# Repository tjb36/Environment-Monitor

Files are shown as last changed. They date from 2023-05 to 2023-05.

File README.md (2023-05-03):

# Environment-Monitor

This is a PCB project to take the ±10V readings from a 3 channel Bartington magnetometer, read them with an ADC and Arduino, and finally post the data over ethernet to a remote InfluxDB database.





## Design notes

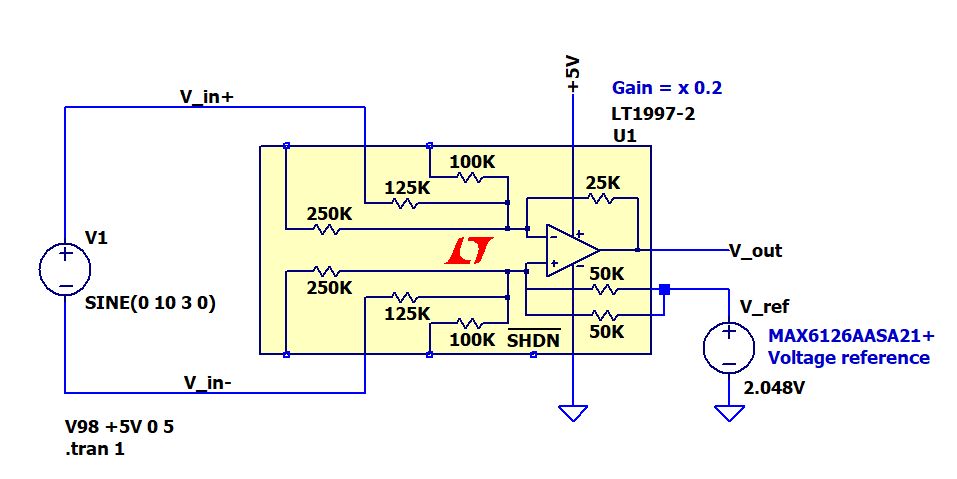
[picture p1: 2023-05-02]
Environment_Monitor_PCB_FILES/Schematic.jpg

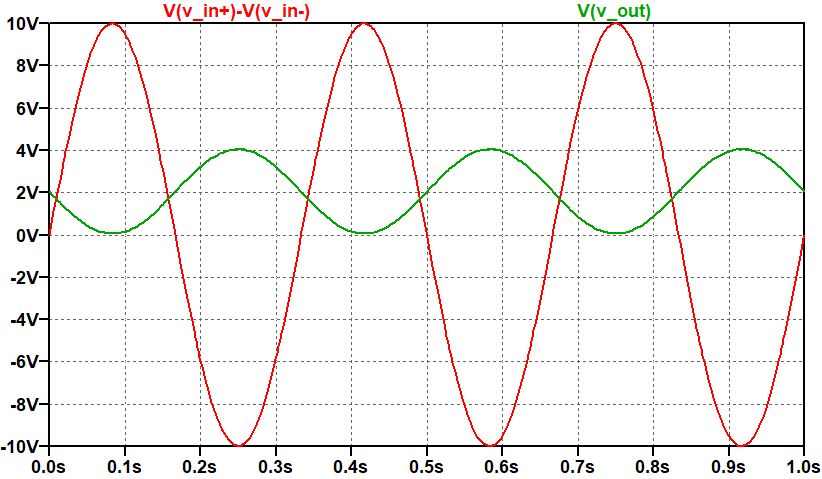
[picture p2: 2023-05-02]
Environment_Monitor_PCB_FILES/waveform.jpg

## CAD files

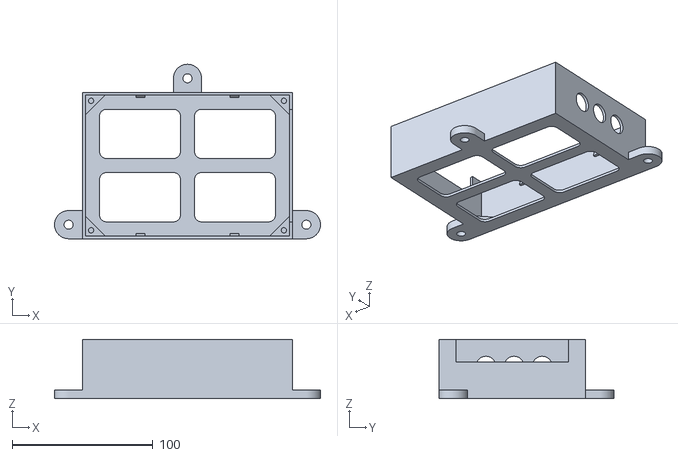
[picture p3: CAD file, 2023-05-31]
Environment_Monitor_CAD/Environment_Monitor_Case-Main Frame.stl
189.0 x 124.0 x 42.0

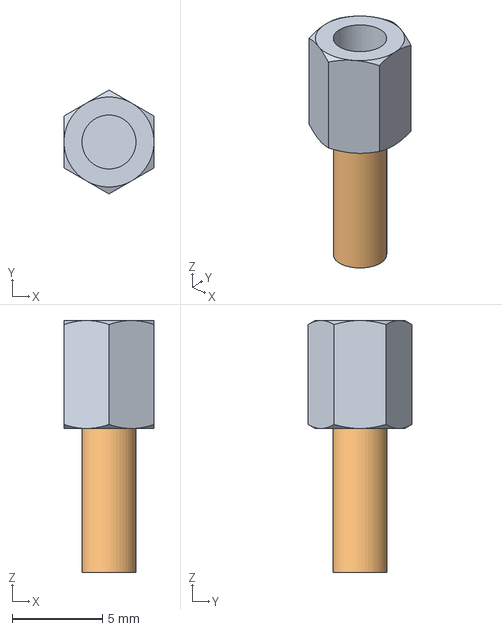
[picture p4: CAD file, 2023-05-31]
Environment_Monitor_CAD/3D/Standoff mf - M3 x 6 across flats 5mm.step
5.00 x 5.77 x 14.0 mm

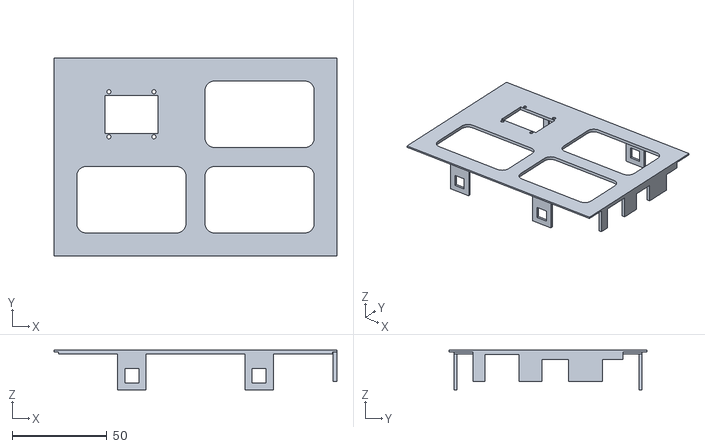
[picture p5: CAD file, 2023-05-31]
Environment_Monitor_CAD/Environment_Monitor_Case-Case Lid.stl
149.0 x 104.0 x 21.0

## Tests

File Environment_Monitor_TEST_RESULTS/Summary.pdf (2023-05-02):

Environment Logger Summary,

# Tests, and Calibration

### T. Barrett

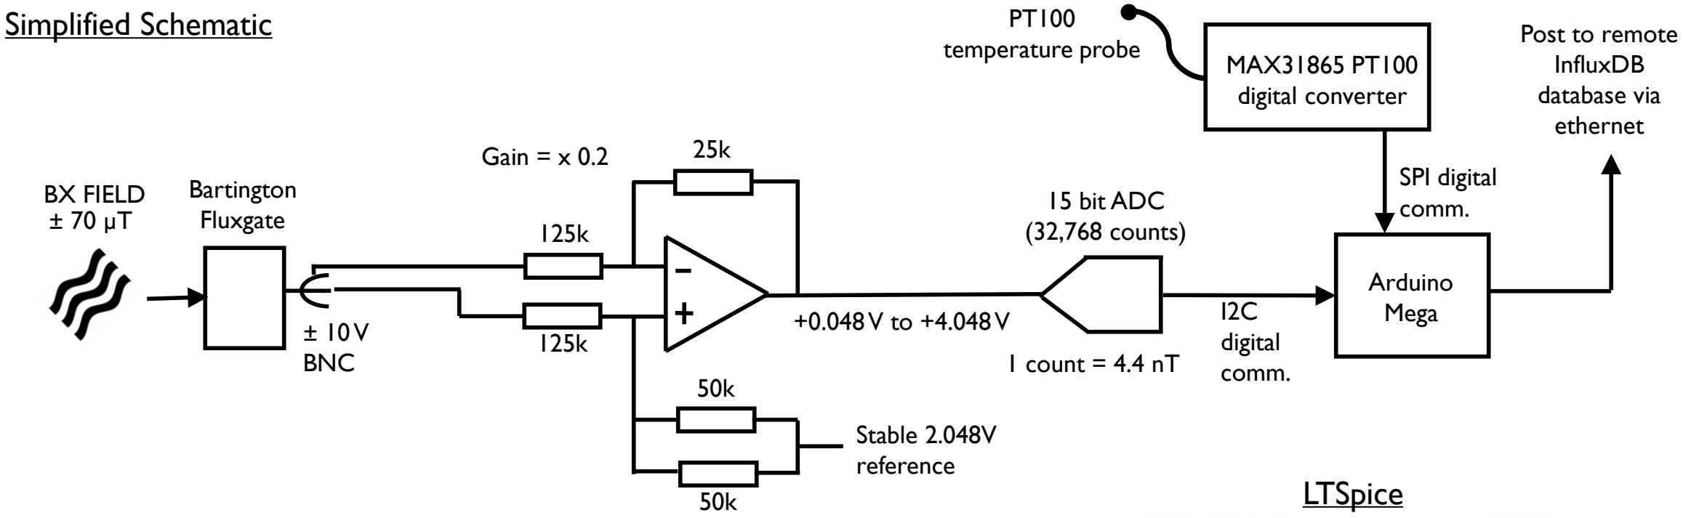
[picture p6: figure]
Stable 2.048V reference; 1 count = 4.4 nT; Bartington; Fluxgate; ± 10 V BNC; digital comm.; Arduino Mega; Post to remote InfluxDB database via ethernet; 15 bit ADC (32,768 counts); Gain = x 0.2; BX FIELD; Simplified Schematic; LTSpice; MAX31865 PT100 digital converter; PT100 temperature probe; SPI digital comm.
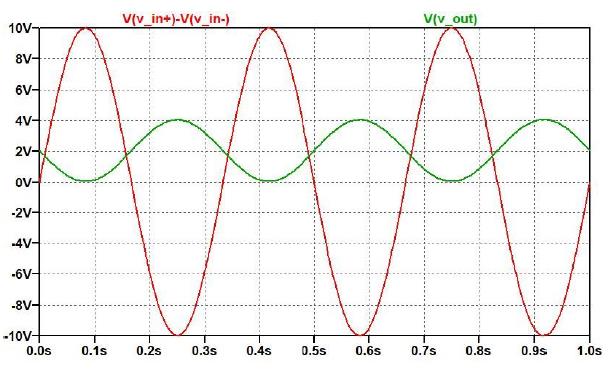
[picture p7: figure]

Repeat for BY on channel 2

Repeat for BZ on channel 3

…

…

Microcontroller Pins Required

ADS1115 (4 channel ADC)

- SCL (serial clock)
- SDA (serial data)
- VDD (+5V)
- GND

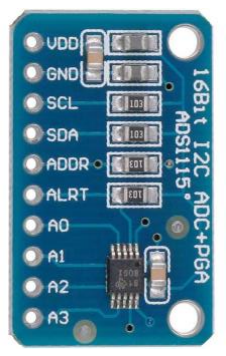
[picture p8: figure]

MAX31865 (PT100 amplifier)

- CLK
- MISO
- MOSI
- CS
- VDD (+5V)
- GND

2-wire I2C

SPI

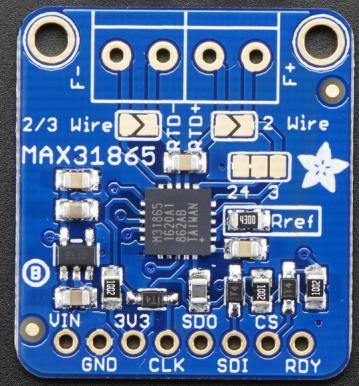
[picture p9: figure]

- Can use hardware SPI or software SPI. Hardware SPI is faster, because there is an internal peripheral device designed to shift the bits out and generate the signals.

Mini W5100 (LAN chip)

SPI

- CLK
- MISO
- MOSI

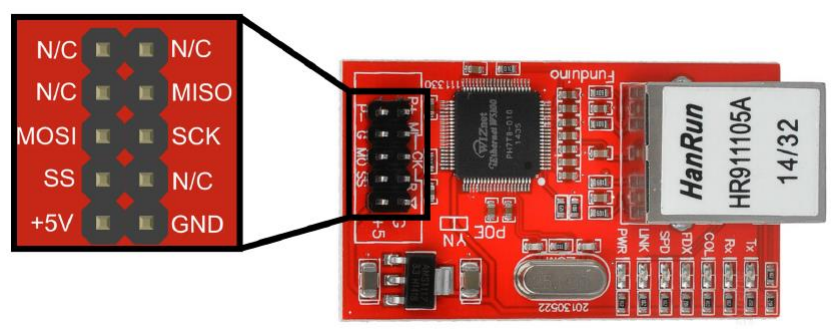
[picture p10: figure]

- CS (use pin 10, because it’s defined in Arduino library)
- VDD (+5V)
- GND
- Arduino Mega hardware SPI pins: | CLK
| MISO
| MOSI 51

50

52

- Arduino Mega I2C pins: SCL SDA D20 D21

- Arduino Nano has 32 KB flash memory (2 KB used by bootloader). So, 30,720 bytes available for program. This is equivalent to 30.72 kilobytes, or 30 kibibytes.
- Arduino Mega has 256 KB memory (8 KB used by bootloader). So should be 248 kibibytes available to use. Which is 248 x 1024 = 253,952 bytes.
- Ethernet sketch requires 18,294 bytes
- Temperature sketch requires 4,004 bytes
- ADC sketch requires 3,236 bytes
- Basic OLED sketch requires 7,016 bytes
- Total is 32,550 bytes…
(more than available on Nano… need to use Arduino Mega)

Microcontroller Memory Required

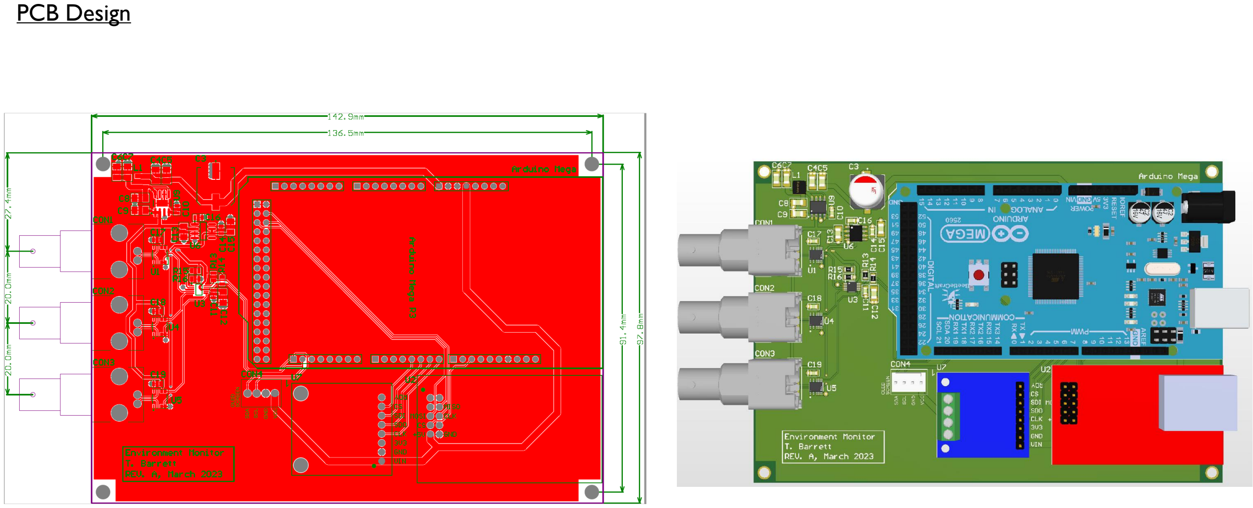
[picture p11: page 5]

PCB Design

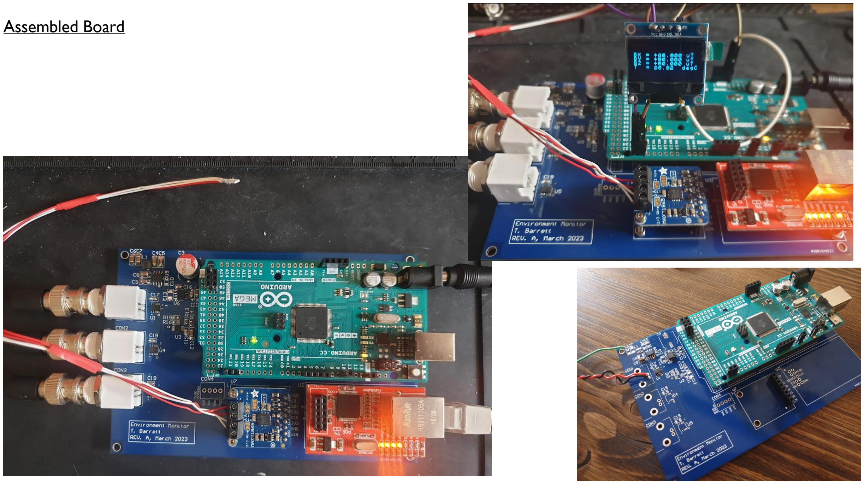
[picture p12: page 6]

Assembled Board

Structure of Firmware

Startup functions → Initialise ethernet chip, ADC, and PT100 converter

Collect N readings from ADC channel 1 and take average (takes 1.73 ms per reading, e.g. 173ms for 100 readings)

Collect N readings from ADC channel 2 and take average (takes 1.73 ms per reading, e.g. 173ms for 100 readings)

Collect N readings from ADC channel 3 and take average (takes 1.73 ms per reading, e.g. 173ms for 100 readings)

Obtain PT100 reading (takes 77 ms)
Connect to remote InfluxDB server, post data, read response, disconnect from server (takes 25 ms)

MAIN LOOP (every X seconds, e.g. every 20 sec)

Update OLED display screen

~620 ms

Power On

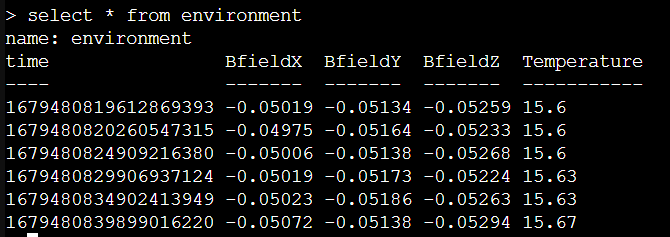
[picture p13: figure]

Data format in InfluxDB
(each datapoint is a field, with no tags).

All fields share a common time-stamp (may be useful later if wanting to do correlation, etc)

ADC Calibration of all channels

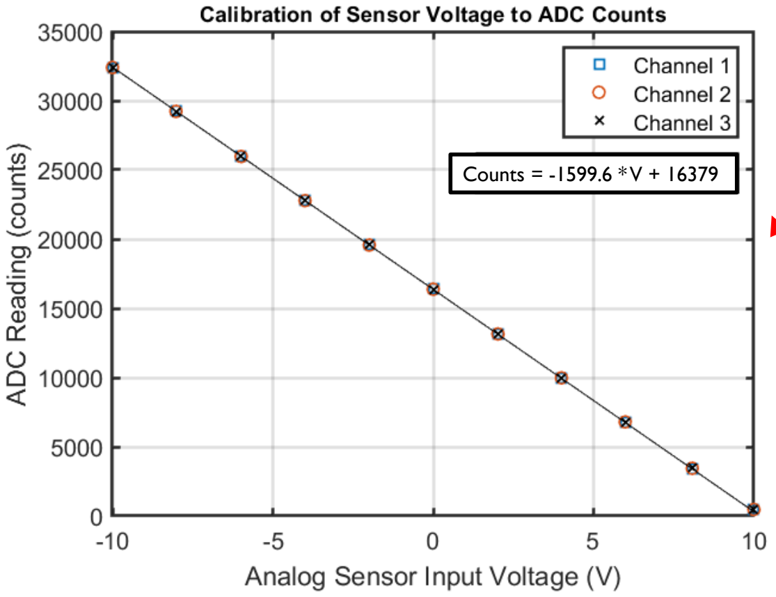
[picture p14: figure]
Counts = -1599.6 * V + 16379

Expected 0.000125 volts per bit from ADC setting gain=1 This is 8000 counts per volt.
Expected additional gain of 0.2 from LT1997-2 funnel amplifier

So expect: 8000 x 0.2 = 1600 counts / volt
This is close to the measured value of 1599.6 counts / volt

Although the ADS1115 ADC is technically a 16 bit ADC (and should therefore go up to 65,536 counts), this is only true when working in differential mode. In that case, one of the 16 bits is the sign bit, and the other 15 bits are for data. However, differential mode requires dedicating x2 of the ADC inputs, and I would need to have then 6 channels available for all 3 magnetic field directions. The ADC only has 4 channels though, so to avoid needing a second ADC, I am running each channel in single-ended mode. This means you can never get negative values, and so effectively sacrifice the sign bit, leaving an effective 15 bit resolution (32,768 values).

Note:

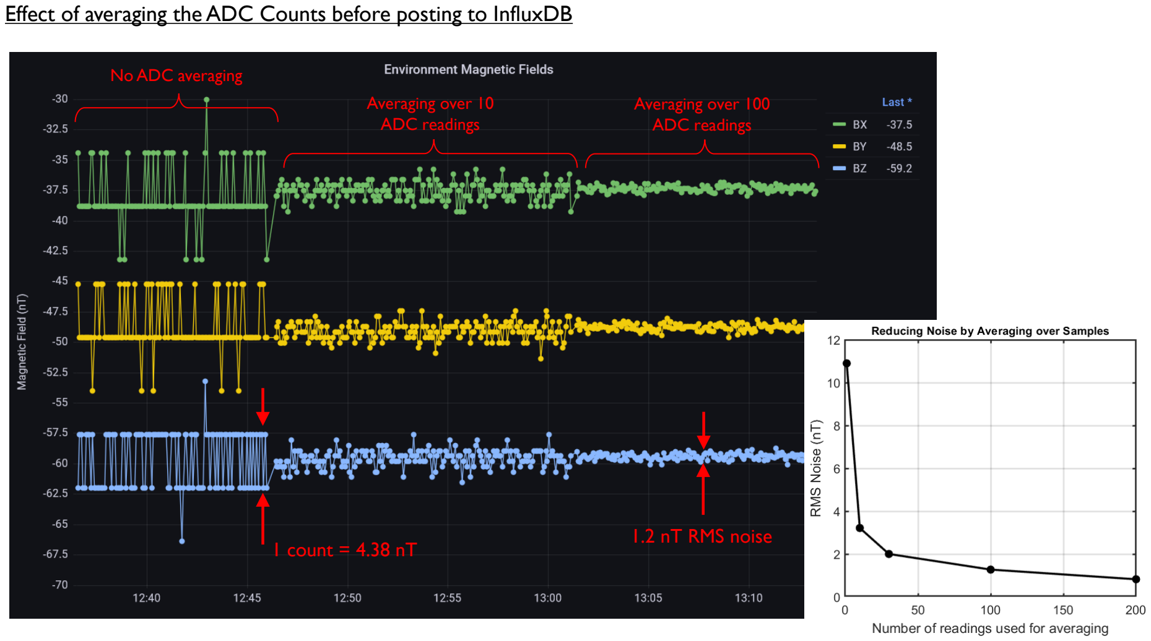
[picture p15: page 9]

Averaging over 100
ADC readings

Averaging over 10
ADC readings

No ADC averaging

1 count = 4.38 nT

Effect of averaging the ADC Counts before posting to InfluxDB

1.2 nT RMS noise


Measuring a 20 Hz sine wave | Measuring a 50 Hz sine wave
Measuring a 100 Hz sine wave | Measuring a 200 Hz sine wave (some aliasing)


- Max and min counts
seems to be around
32330 and 520 counts

→ means I am able to
capture the full +-10V
range successfully.
- 5 Hz sine wave, 20 V p-p (+-10V) | • Measuring the time to collect 10 values from ADC:
- Corresponds to 577 samples / second (should be able to measure up to 288 Hz signals without aliasing)


- BZ changed by 12 nT when Temperature went from 16 to 35 °C
- BX changed by 6 nT when Temperature went from 16 to 35 °C
- BZ changed by 12 nT when Temperature went from 35 to 52 °C
- BX changed by 5 nT when Temperature went from 35 to 52 °C
- BZ changes by 12 nT in 18°C, or 0.67 nT / °C
- BX changes by 6 nT in 18°C, or 0.33 nT / °C
- Applied a BX field of -34990 nT (5V) , and a BZ field of 0 nT.
- At 50°C, we can expect a change of ~12-24 nT from room temperature. This corresponds to 2.5 – 5.5 ADC counts.
- LT1997-2 has a gain error of 1 ppm/°C (0.2 ppm/°C typical).

ADS1115 datasheet says
we can expect 0.015%
change in gain when
increasing from room
temperature up to 50°C

Checking Behaviour of System when Heated to 50°C


Temperature Dependence of Calibration Factors

- A temperature-dependent calibration factor was therefore included in the firmware. (i.e. first we measure the temperature, and then calculate the most appropriate calibration factors – offset and slope - to use)

Behaviour of system when heated to 50°C after adding temperature-dependent calibration


Since the system is heated up fast (in an oven), the PT100 probe heats up faster than the analog circuitry on the PCB, and so there is a delay of around 5 minutes before the calibration becomes accurate.

In the real system, when dealing with slow changes to the room temperature, this will not be present.

The error in the magnetic field reading is now less than 1nT at 50 °C.

This is a big improvement on the error of 24nT before, when the temperature –dependent calibration was not used.

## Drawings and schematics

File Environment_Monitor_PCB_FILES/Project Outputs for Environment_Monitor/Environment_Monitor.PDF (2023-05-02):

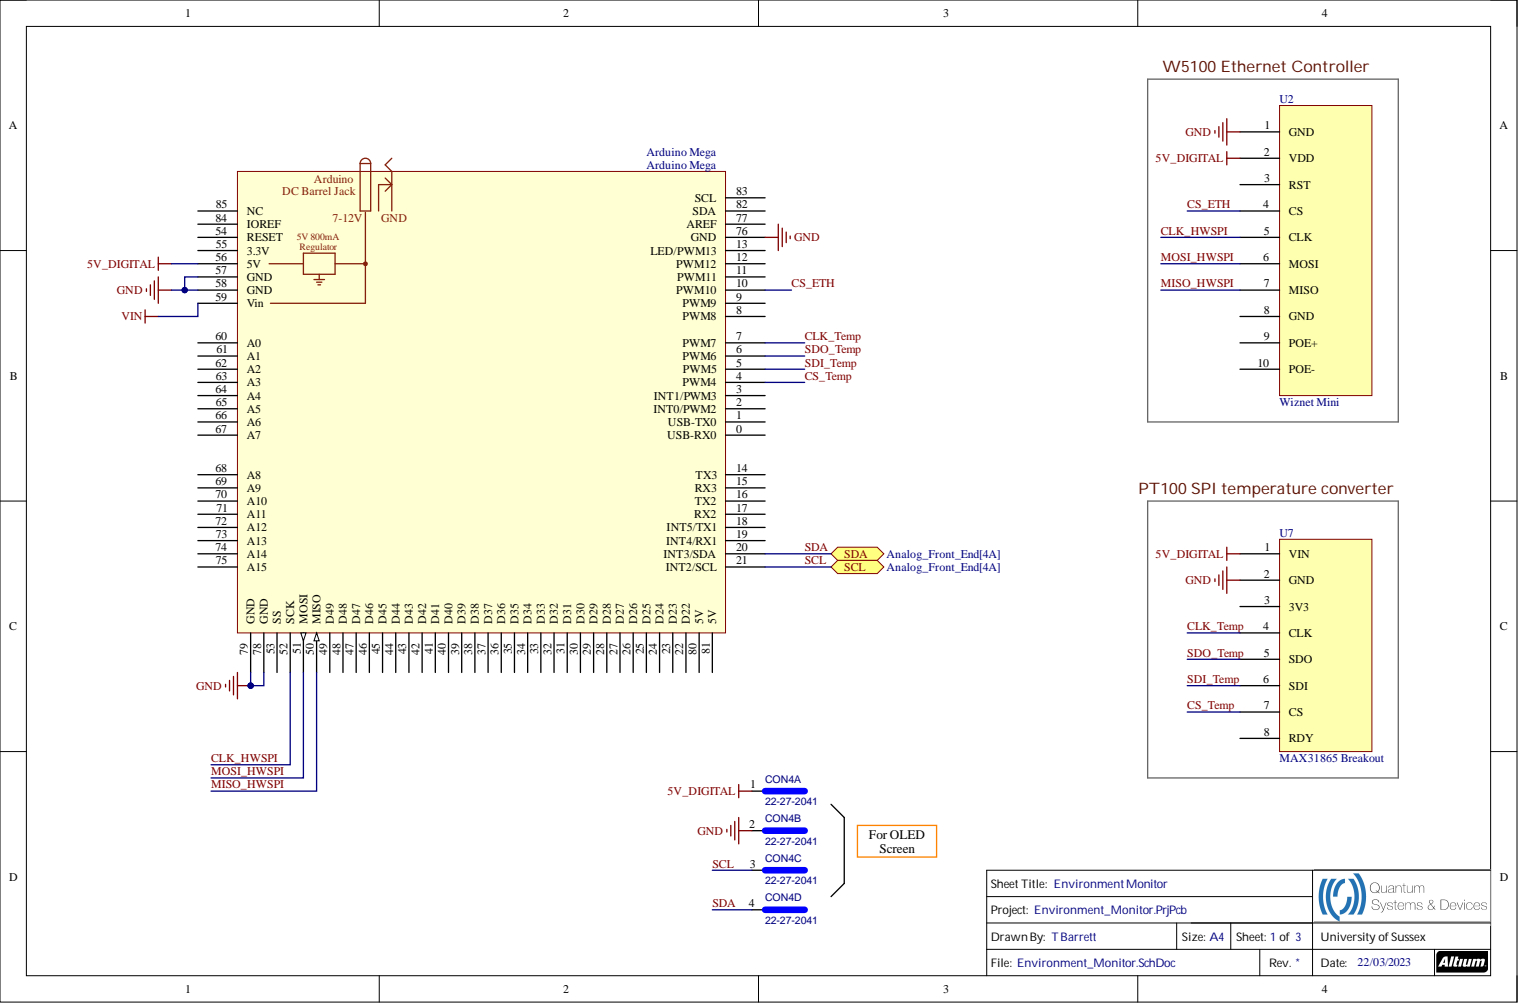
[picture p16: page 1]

D22 22 D23 23 D24 24 D25 25 D26 26 D27 27 D28 28 D29 29 D30 30 D31 31 D32 32 D33 33 D34 34 D35 35 D36 36 D37 37 D38 38 D39 39 D40 40 D41 41 D42 42 D43 43 D44 44 D45 45 D46 46 D47 47 D48 48 D49 49 MISO 50 MOSI 51 SCK 52 SS 53

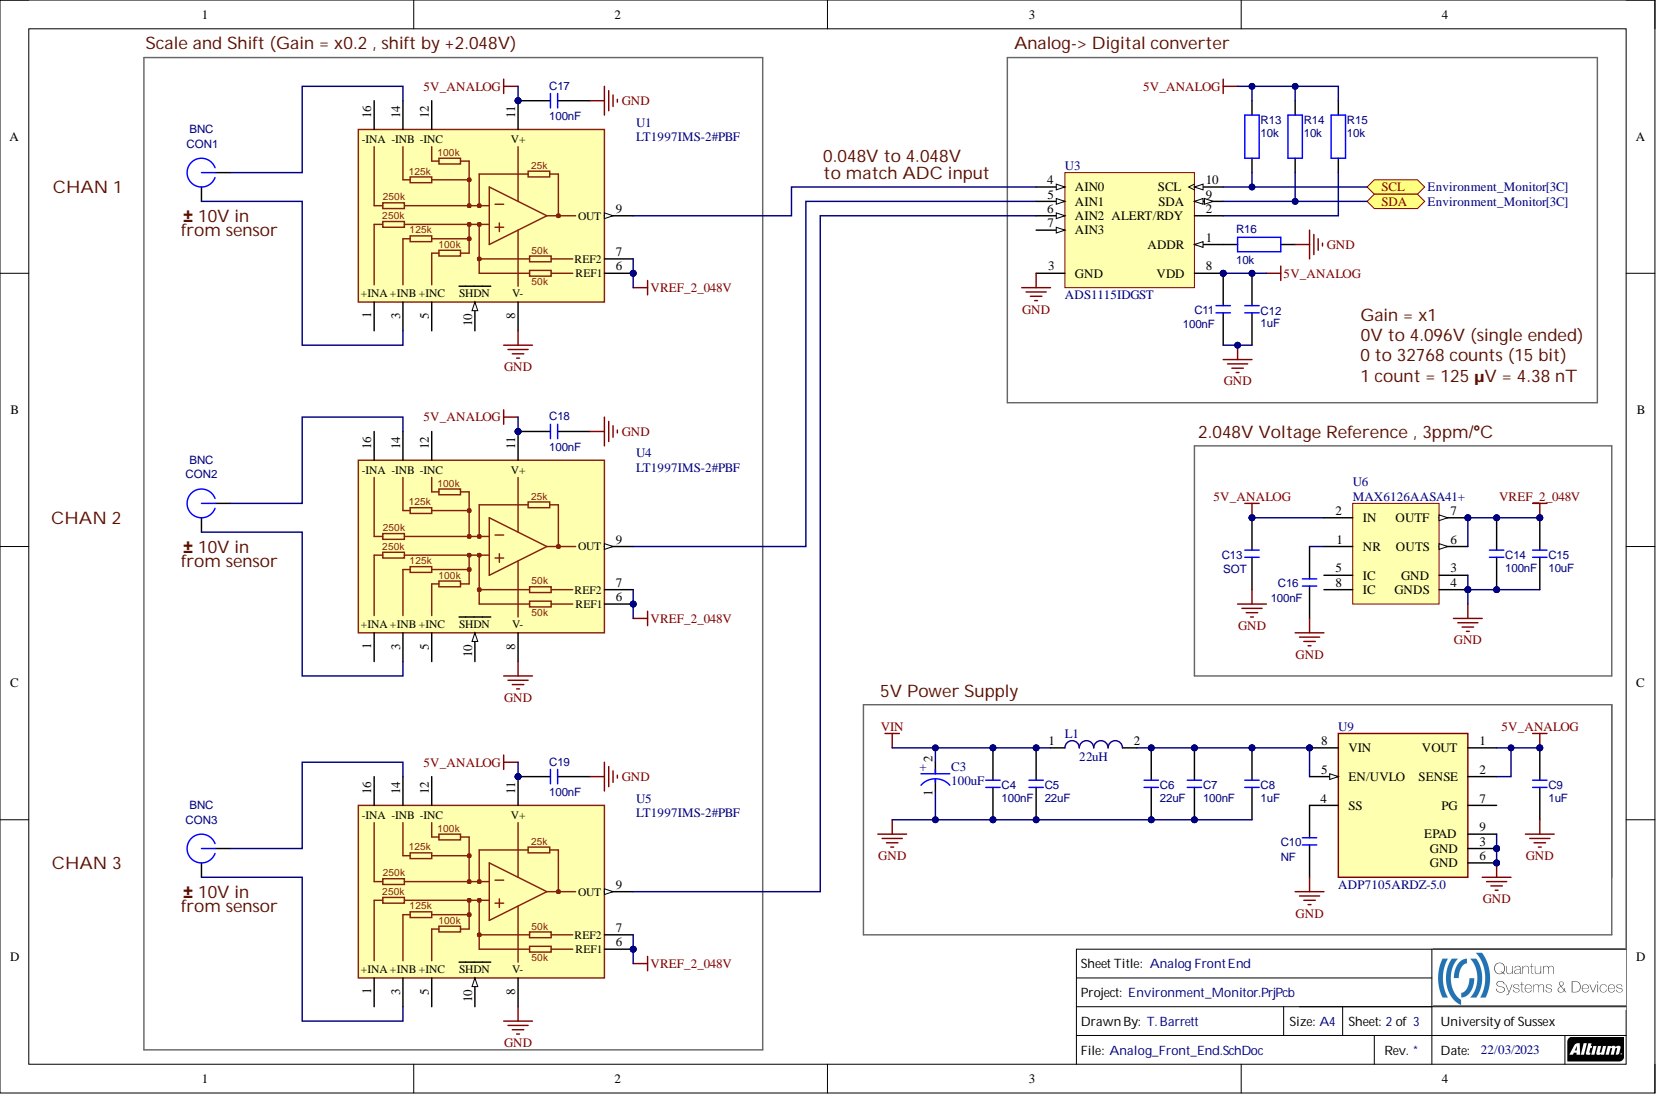
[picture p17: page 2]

6 REF2 7 | G | 7

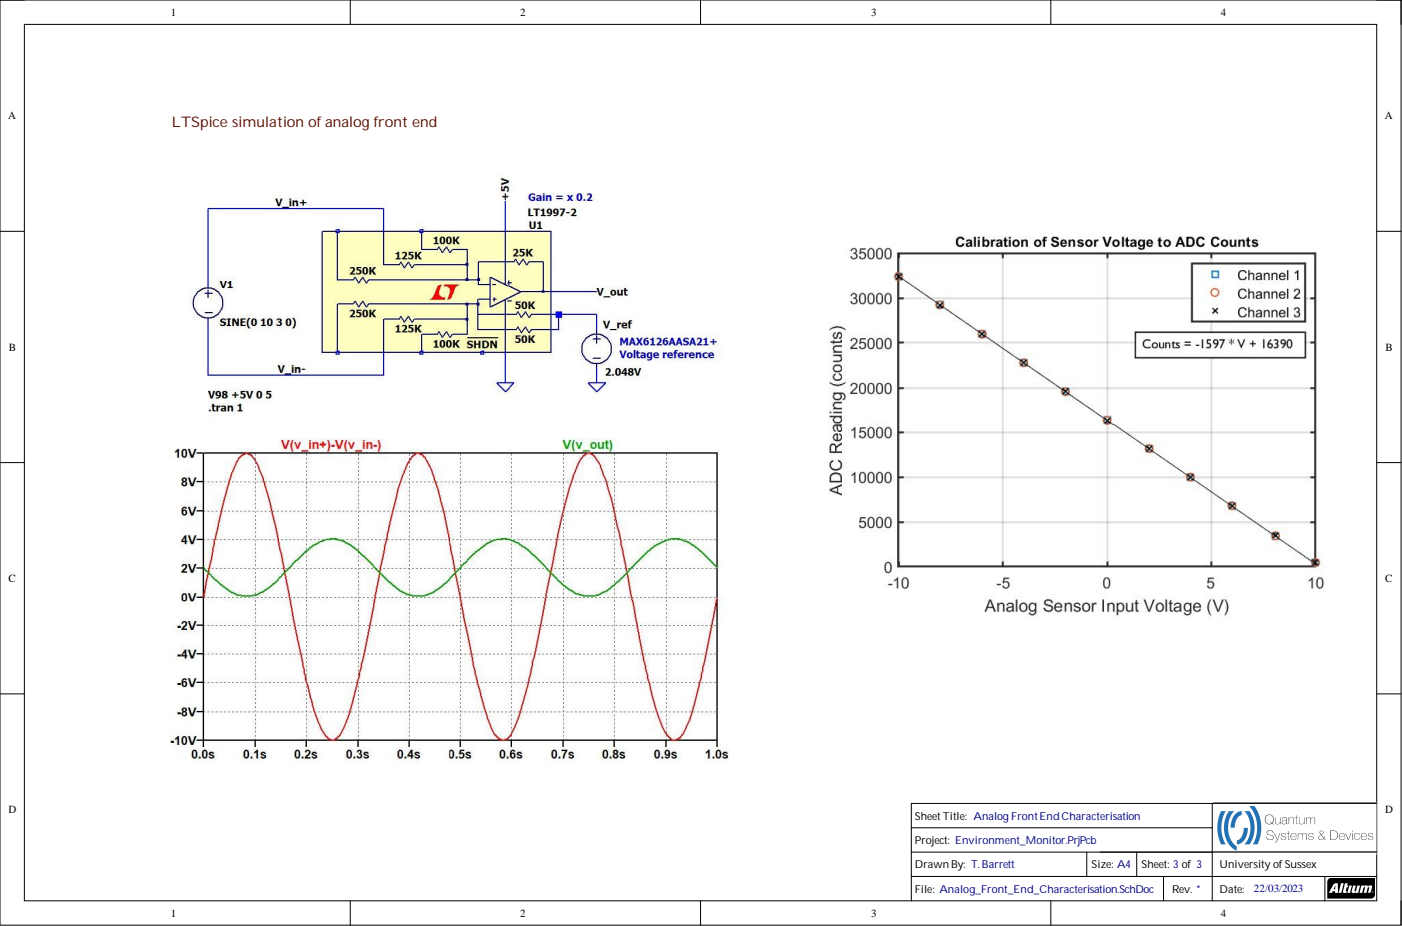
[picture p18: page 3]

LTSpice simulation of analog front end

Analog Front End Characterisation

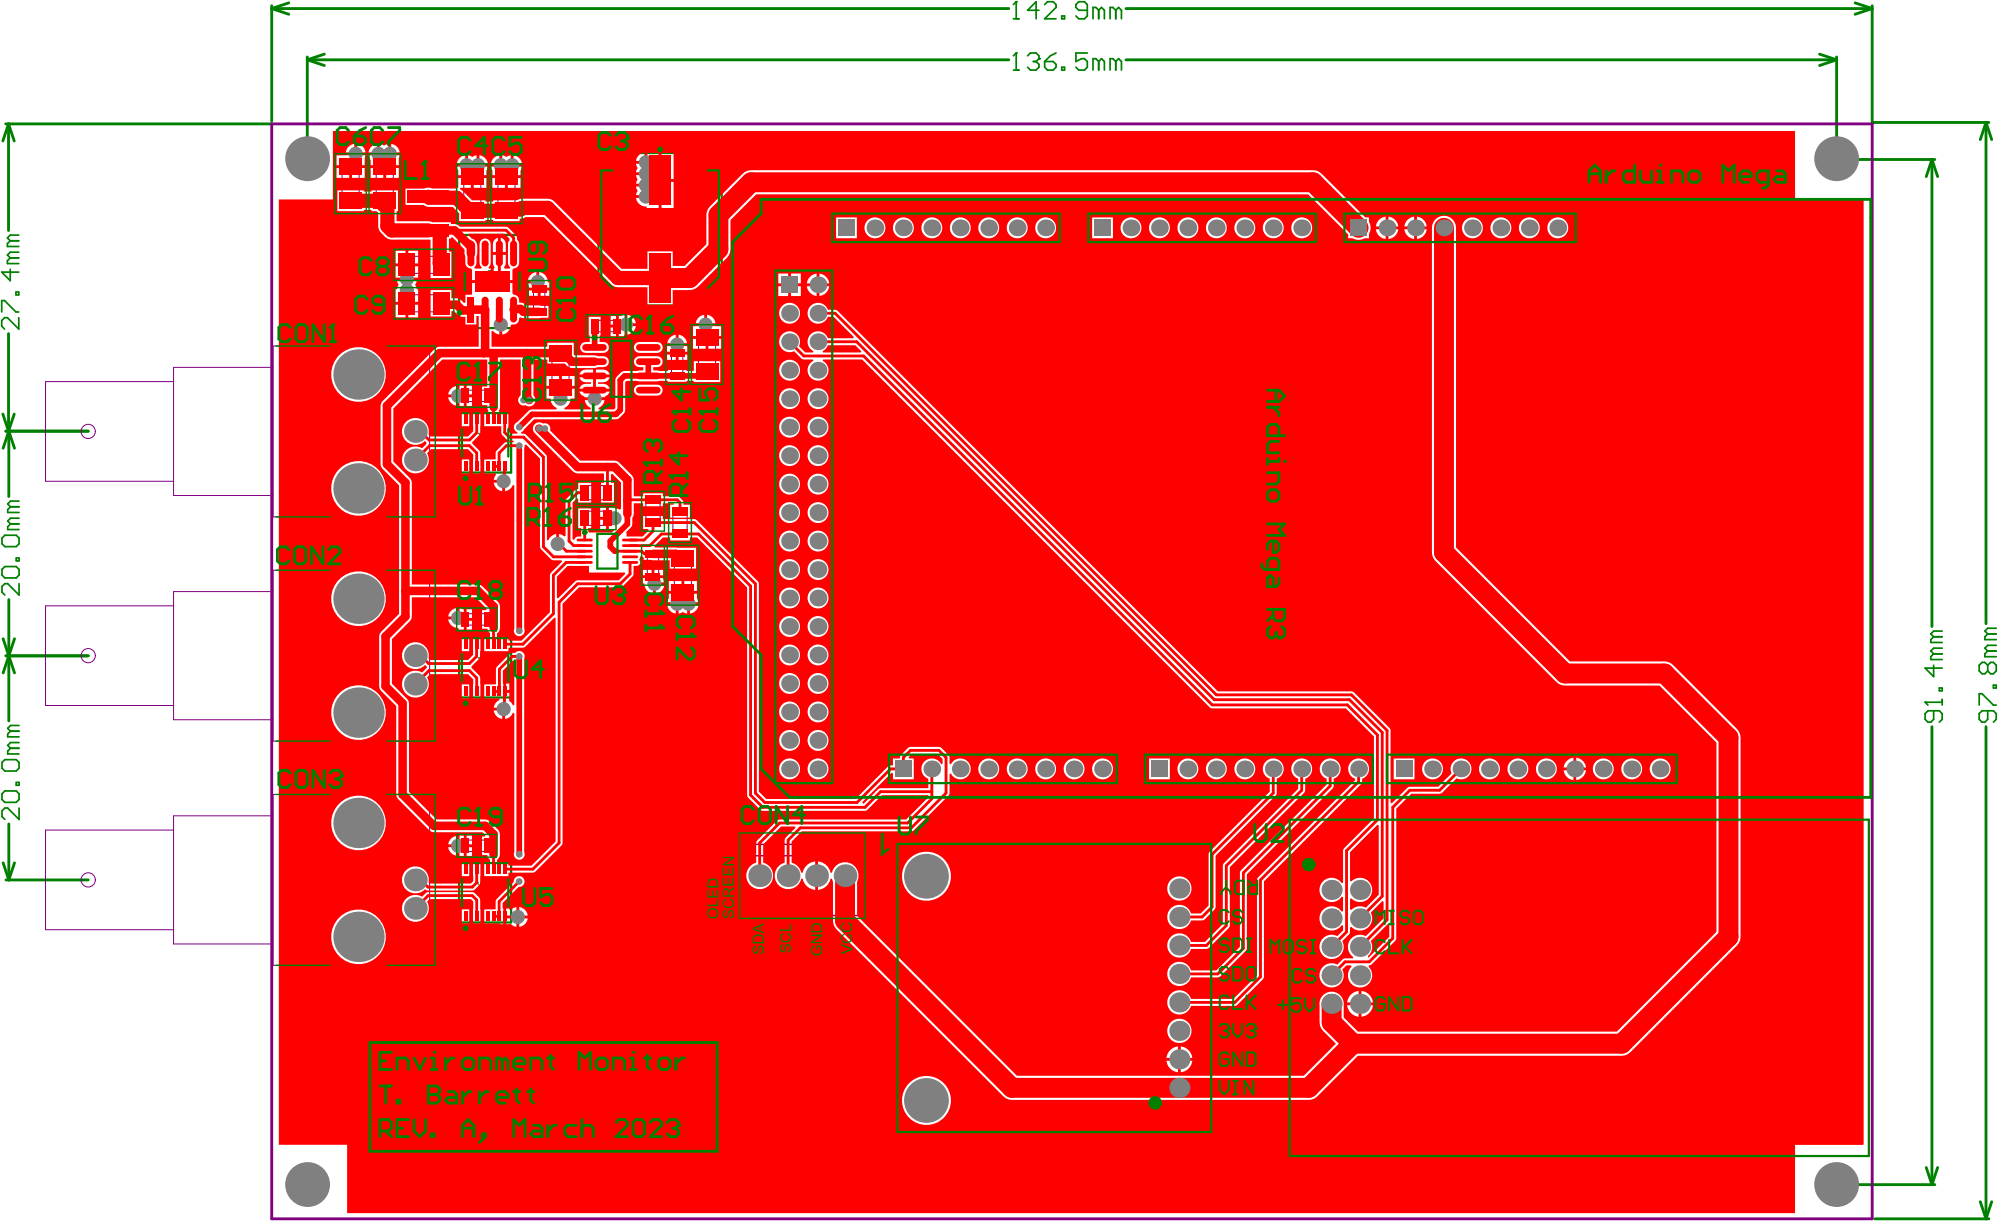
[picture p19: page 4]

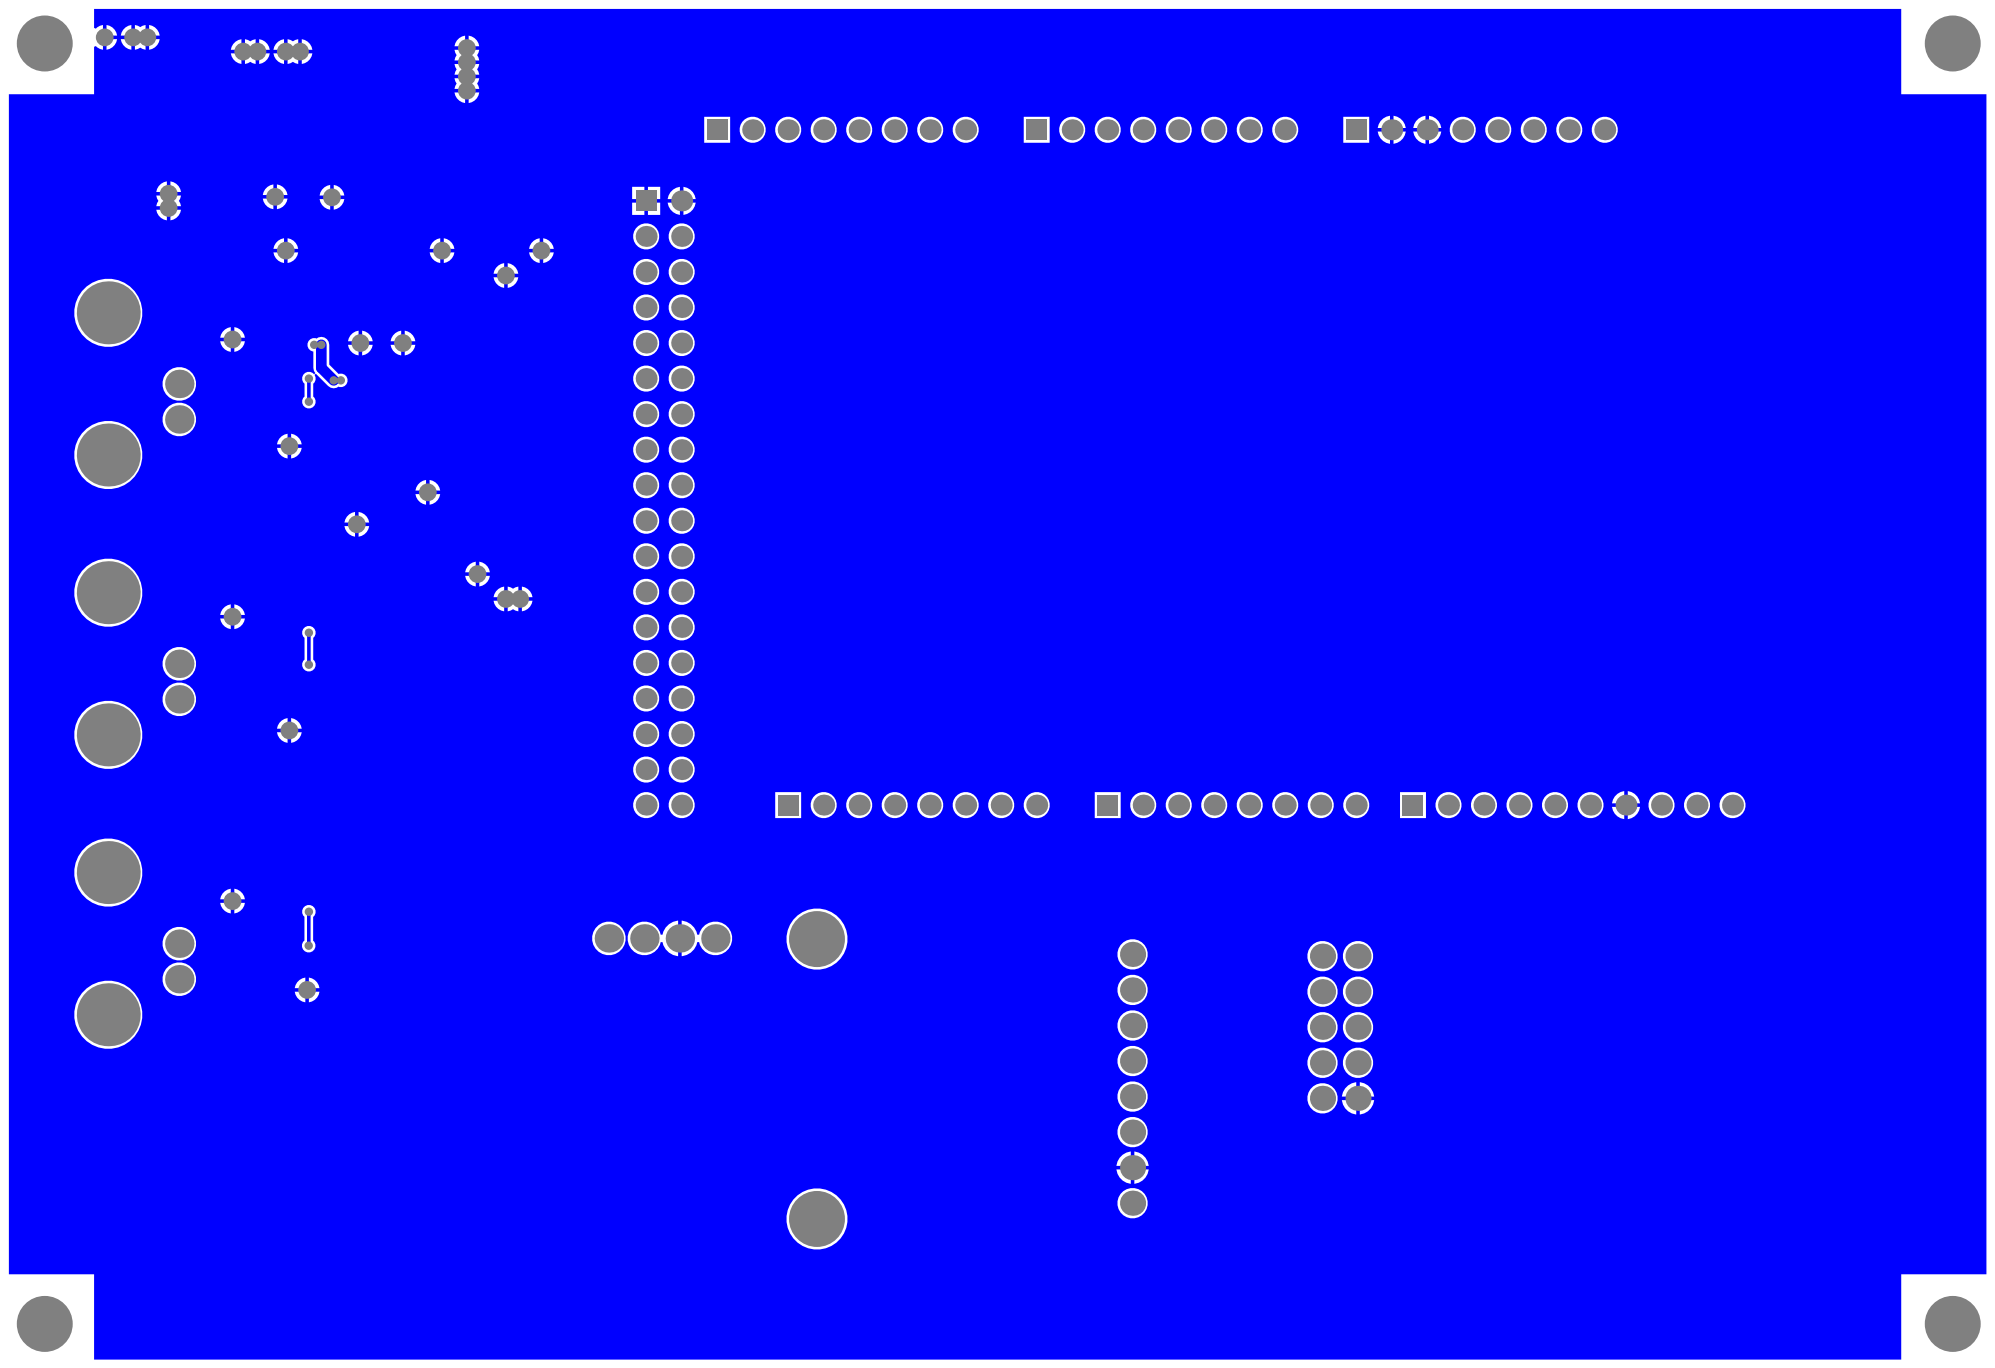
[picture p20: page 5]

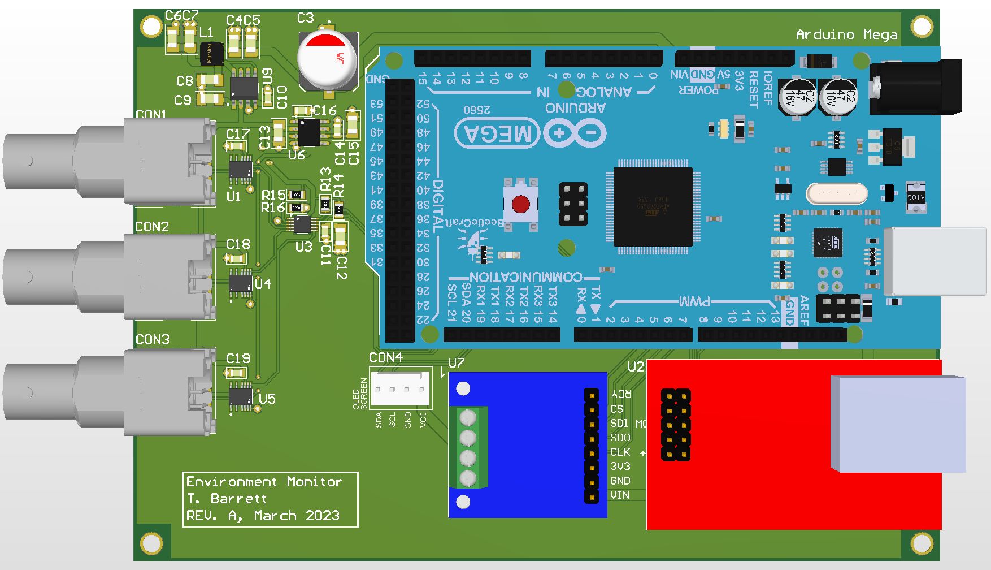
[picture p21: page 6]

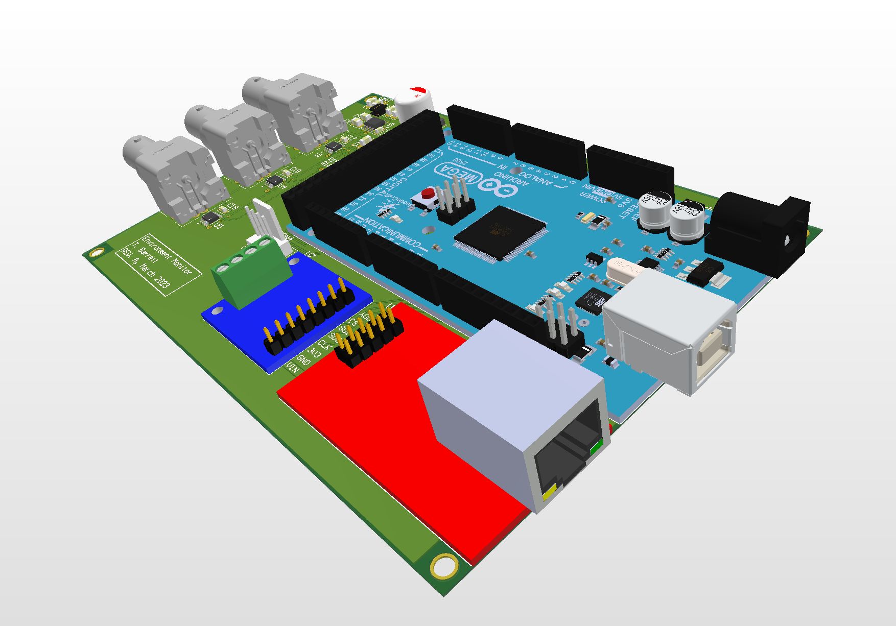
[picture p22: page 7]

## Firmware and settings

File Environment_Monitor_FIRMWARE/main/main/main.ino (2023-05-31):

#include <Ethernet.h>
#include <EthernetUdp.h>
#include <ADS1115_lite.h>
#include <Adafruit_MAX31865.h>
#include <U8x8lib.h>
#include <Wire.h>

// Class for running the UDP connection /////////////////////
class UDPClient{
  public:
    UDPClient() = delete;
    UDPClient( const unsigned int l_port ):m_port(l_port){}
    virtual ~UDPClient() = default;
    UDPClient( const UDPClient& l_client ) = delete;
    UDPClient& operator = ( const UDPClient& l_client ) = delete;

    bool setup(){
      if( m_udp.begin( m_port )){
        m_setup = true;
        return true;
      }else{
        m_setup = false;
        return false;
      }
    }

    bool recievePacket(){
      if( m_setup ){
        m_currentPacketSize = m_udp.parsePacket();
        if( m_currentPacketSize ){
          // read the packet into packetBuffer
          m_udp.read( m_packetBuffer, UDP_TX_PACKET_MAX_SIZE );
          return true;
        }
      }
      return false;
    }

    unsigned int getRemotePort() const{
      return m_remotePort;
    }

    IPAddress getRemoteIP() const{
      return m_remoteIP;
    }

    void setRemotePort( unsigned int port ){
      m_remotePort = port;
    }

    void setRemoteIP( IPAddress IP ){
      m_remoteIP = IP;
    }

    int getMessageLength() const{
      return m_currentPacketSize;
    }

    const char* getMessage() const{
      return m_packetBuffer;
    }

    void flushPacketBuffer(){
      for( int i = 0; i < UDP_TX_PACKET_MAX_SIZE; i++ ){
        m_packetBuffer[i] = '\0';
      }
    }

    bool writeMessage( const char* message ){
      if( m_setup ){
        m_udp.beginPacket(getRemoteIP(), getRemotePort());
        m_udp.write(message);
        m_udp.endPacket();
        return true;
      }
      return false;
    }

  private:
    EthernetUDP m_udp;
    const unsigned int m_port;

    int m_currentPacketSize = 0;
    char m_packetBuffer[UDP_TX_PACKET_MAX_SIZE];

    bool m_setup = false;

    unsigned int m_remotePort;
    IPAddress m_remoteIP;
};
/////////////////////////////////////////////////////////////////////

// TIMING REGULAR INTERVALS VARIABLES ///
const unsigned long samplingInterval = 3000;    // How often to collect a batch of readings in ms (e.g. every 20 sec = 20000 ms)
unsigned long previousSampledMillis = 0;        // Time at which previous sample was acquired
unsigned long currentMillis = 0;                // Current time elapsed since program started in ms

////// ADC VARIABLES /////
ADS1115_lite adc(ADS1115_DEFAULT_ADDRESS); //Initializes wire library, sets private configuration variables to ADS1115 default(2.048V, 128SPS, Differential mode between  AIN0 and AIN1.  The Address parameter is not required if you want default
int16_t Raw;
int N = 100;    // Number of samples to use for averaging
long Raw_runningsum;

////// OLED SCREEN VARIABLES ///
U8X8_SSD1306_128X64_NONAME_HW_I2C u8x8(U8X8_PIN_NONE);
char result1[7]; // Preallocate character arrays for text to appear on screen
char result2[7];
char result3[7];
char result4[7];

////// PT100 VARIABLES ///
Adafruit_MAX31865 thermo = Adafruit_MAX31865(4, 5, 6, 7);
#define RREF      430.0 // The value of the Rref resistor. Use 430.0 for PT100
#define RNOMINAL  100.0 // The 'nominal' 0-degrees-C resistance of the sensor, 100.0 for PT100

////// ETHERNET VARIABLES /////
EthernetClient client;
byte mac[] = { 0xDE, 0xAD, 0xBE, 0xEF, 0xFE, 0xEB };
unsigned int localPort = 8040;

UDPClient udpClient( localPort );

IPAddress SERVER_NAME(192, 168, 10, 2);
int    SERVER_PORT = 8089;
int    INFLUX_SENDER_PORT = 8089;
String INFLUXDB_DATABASE = "quantbatt";
String INFLUXDB_USERNAME = "";
String INFLUXDB_PASSWORD = "";
String HTTP_METHOD = "POST";

String SERVER_NAME_STR = String(SERVER_NAME[0]) + "." + SERVER_NAME[1] + "." + SERVER_NAME[2] + "." + SERVER_NAME[3] ;
String endPoint = "/write?db=" + INFLUXDB_DATABASE + "&u=" + INFLUXDB_USERNAME + "&p=" + INFLUXDB_PASSWORD;

UDPClient udpInfluxClient( INFLUX_SENDER_PORT );

String payload = "";  //data for HTTP Post;
char response_buffer[500];
int index = 0;
int response_code;
bool NetworkConnected;
///////////////////////////////////////////////////////

float average_counts;
float Bfield_X_Sensorvoltage;
float Bfield_Y_Sensorvoltage;
float Bfield_Z_Sensorvoltage;
float Bfield_X;
float Bfield_Y;
float Bfield_Z;
float T;

float microTeslaPerVolt = 7.0; // Should be 7 uT/V for real device

int interuptRate;
bool postDataPackets = true;
const String axis[] = {"X", "Y", "Z"};

String experimentID = "none";

void setup() {
  Serial.begin(57600);

  // Start OLED display screen, and display a welcome message /////
  u8x8.begin();
  u8x8.setPowerSave(0);
  u8x8.setFont(u8x8_font_victoriamedium8_r);
  u8x8.drawString(4, 0, "Welcome!");
  u8x8.drawString(2, 2, "Environment");
  u8x8.drawString(4, 3, "Monitor");
  u8x8.drawString(2, 6, "Starting...");
  delay(3000);
  /////////////////////////////////////////////////////////////////


  // SET UP ETHERNET //
  u8x8.clearDisplay();
  u8x8.drawString(0, 2, "Connecting to");
  u8x8.drawString(0, 3, "network...");
  pinMode(10, OUTPUT);   // SPI SS pin for most Arduino models (need to connect)
  Serial.println("Waiting for IP...");
  if (Ethernet.begin(mac) == 0) { // Putting only mac here means dhcp will be used (and assigned ip address will appear in router table)
    NetworkConnected = false;
    u8x8.drawString(2, 6, "Failed!");
    Serial.println("Network Connection Failed");
  } else {
    NetworkConnected = true;
    u8x8.drawString(11, 3, "Done!");
    u8x8.drawString(2, 6, IpAddress2String(Ethernet.localIP()).c_str() );
    Serial.println(IpAddress2String(Ethernet.localIP()));
    Serial.println("Network Connected");
    Serial.println(Ethernet.localIP());

    udpClient.setup();
    udpInfluxClient.setup();
    udpInfluxClient.setRemotePort( SERVER_PORT );
    udpInfluxClient.setRemoteIP( SERVER_NAME );
  }

  delay(3000);
  /////////////////////

  // SET UP ADC ///////
  adc.setGain(ADS1115_REG_CONFIG_PGA_4_096V);
  adc.setSampleRate(ADS1115_REG_CONFIG_DR_860SPS); // Sample rate affects noise (see Fig. 14 and 15 of datasheet)
  Wire.setClock(400000);
  /////////////////////

  // SET UP PT100 /////
  thermo.begin(MAX31865_4WIRE);  // initialize the sensor
  /////////////////////

  // Initialise parameters on the OLED display screen /////////////
  u8x8.clearDisplay();
  u8x8.drawString(0, 0, IpAddress2String(Ethernet.localIP()).c_str());
  u8x8.drawString(0, 2, "BX = ");
  u8x8.drawString(5, 2, "00.000");
  u8x8.drawString(13, 2, "uT");
  u8x8.drawString(0, 3, "BY = ");
  u8x8.drawString(5, 3, "00.000");
  u8x8.drawString(13, 3, "uT");
  u8x8.drawString(0, 4, "BZ = ");
  u8x8.drawString(5, 4, "00.000");
  u8x8.drawString(13, 4, "uT");
  u8x8.drawString(0, 5, "T  = ");
  u8x8.drawString(5, 5, "00.00");
  u8x8.drawString(12, 5, "degC");
  /////////////////////////////////////////////////////////////////
  //u8x8.setFont(u8x8_font_chroma48medium8_r);



  // Set up interupt for sending influx data //////////////////////
  noInterrupts();           // disable all interrupts
  TCCR1A = 0;
  TCCR1B = 0;

  interuptRate = 34286;   // preload timer 65536-16MHz/256/2Hz
  
  TCNT1 = interuptRate;   // preload timer
  TCCR1B |= (1 << CS12);    // 256 prescaler 
  TIMSK1 |= (1 << TOIE1);   // enable timer overflow interrupt
  interrupts();             // enable all interrupts
  /////////////////////////////////////////////////////////////////
}

ISR( TIMER1_OVF_vect ){        // interrupt service routine
  TCNT1 = interuptRate;   // preload timer

  // Post data packets to influx if requested
  if( postDataPackets ){
    // Construct InfluxDB payload
    float flux[] = {Bfield_X, Bfield_Y, Bfield_Z};
    String payload = "";

    for( int i = 0; i < 3; i++ ){
      payload = "bartington,axis=" + axis[i] + ",experiment_ID=" + experimentID + " flux=" + String(flux[i], 5);

      // Send values to remote InfluxDB database
      if (NetworkConnected) {
        udpInfluxClient.writeMessage( payload.c_str());
      }
    }

    payload = "thermocouple,experiment_ID=" + experimentID + " temperature=" + String(T, 5);
    // Send values to remote InfluxDB database
    if (NetworkConnected) {
      udpInfluxClient.writeMessage( payload.c_str());
    }
  }
}

void loop() {

  udpClient.recievePacket();
  
  String input = udpClient.getMessage();

  String command = input.substring( 0, 8 );
  String action = input.substring( 9 );

  if( command.equals( "setExpID" )){
    experimentID = action;
  }
  if( command.equals( "startDAq" )){
    postDataPackets = true;
  }
  if( command.equals( "stop-DAq" )){
    postDataPackets = false;
  }
  if( command.equals( "setDataR" )){
    if( action.equals("slow") ){
      interuptRate = 34286; // preload timer 65536-16MHz/256/2Hz
    }
    if( action.equals( "standard" )){
      interuptRate = 64286; // preload timer 65536-16MHz/256/50Hz
    }
    if( action.equals( "fast" )){
      interuptRate = 64911; // preload timer 65536-16MHz/256/100Hz
    }
  }
  if( command.equals("setSampA" )){
    int rate = action.toInt();
    if( !(rate <= 0 )){
      N = rate;
    }
  }

  udpClient.flushPacketBuffer();

  //Measure the temperature using PT100 probe
  T = thermo.temperature(RNOMINAL, RREF);

  // Calculate temperature-dependent calibration factors for converting from ADC counts to sensor voltage
  float SLOPE = -0.01474697320 * T - 1599.32272039864;
  float OFFSET = 0.14383886517 * T + 16376.1858163842;

  // Read Channel #1 ///////////////////
  average_counts = collect_ADC_averagecounts(0);
  Bfield_X_Sensorvoltage = (average_counts - OFFSET) / SLOPE;
  Bfield_X_Sensorvoltage = Bfield_X_Sensorvoltage + 0.00;   // Minor correction to each channels reading (on the order of 100uV only)
  Bfield_X = Bfield_X_Sensorvoltage * microTeslaPerVolt;
  //////////////////////////////////////

  // Read Channel #2 ///////////////////
  average_counts = collect_ADC_averagecounts(1);
  Bfield_Y_Sensorvoltage = (average_counts - OFFSET) / SLOPE;
  Bfield_Y_Sensorvoltage = Bfield_Y_Sensorvoltage + 0.00;
  Bfield_Y = Bfield_Y_Sensorvoltage * microTeslaPerVolt;
  //////////////////////////////////////

  // Read Channel #3 ///////////////////
  average_counts = collect_ADC_averagecounts(2);
  Bfield_Z_Sensorvoltage = (average_counts - OFFSET) / SLOPE;
  Bfield_Z_Sensorvoltage = Bfield_Z_Sensorvoltage + 0.00;
  Bfield_Z = Bfield_Z_Sensorvoltage * microTeslaPerVolt;
  //////////////////////////////////////

  updateOLED(Bfield_X,Bfield_Y,Bfield_Z,T);

  delay(1000);
}


float collect_ADC_averagecounts(int channel) {

  switch (channel) {
    case 0:
      adc.setMux(ADS1115_REG_CONFIG_MUX_SINGLE_0); //Set single ended mode between AIN0 and GND
      break;
    case 1:
      adc.setMux(ADS1115_REG_CONFIG_MUX_SINGLE_1); //Set single ended mode between AIN1 and GND
      break;
    case 2:
      adc.setMux(ADS1115_REG_CONFIG_MUX_SINGLE_2); //Set single ended mode between AIN2 and GND
      break;
  }

  Raw_runningsum = 0;
  for (int i = 0; i < N; i++) {
    adc.triggerConversion(); //Start a conversion.  This immediatly returns
    Raw = adc.getConversion(); //This polls the ADS1115 and wait for conversion
    Raw_runningsum = Raw_runningsum + Raw;
  }
  average_counts = (float)Raw_runningsum / (float)N ;
  return average_counts;
}

String IpAddress2String(const IPAddress& ipAddress)
{
  return String(ipAddress[0]) + String(".") +
         String(ipAddress[1]) + String(".") +
         String(ipAddress[2]) + String(".") +
         String(ipAddress[3]);
}

void updateOLED(float Bfield_X, float Bfield_Y, float Bfield_Z, float T){
  // Convert floats to character arrays, so that they can be printed to screen
  u8x8.clearDisplay();
  dtostrf(Bfield_X, 5, 3, result1);
  dtostrf(Bfield_Y, 5, 3, result2);
  dtostrf(Bfield_Z, 5, 3, result3);
  dtostrf(T,  5, 2, result4);

  if (Bfield_X >= 0) {
    u8x8.drawString(5, 2, "+");
    u8x8.drawString(6, 2, result1);
  }
  else {
    u8x8.drawString(5, 2, result1);
  }

  if (Bfield_Y >= 0) {
    u8x8.drawString(5, 3, "+");
    u8x8.drawString(6, 3, result2);
  }
  else {
    u8x8.drawString(5, 3, result2);
  }

  if (Bfield_Z >= 0) {
    u8x8.drawString(5, 4, "+");
    u8x8.drawString(6, 4, result3);
  }
  else {
    u8x8.drawString(5, 4, result3);
  }

  u8x8.drawString(5, 5, result4);

  if( postDataPackets ){
    u8x8.drawString(0, 1, "Posting");
  }else{
    u8x8.drawString(0, 1, "Not Posting");
  }
}

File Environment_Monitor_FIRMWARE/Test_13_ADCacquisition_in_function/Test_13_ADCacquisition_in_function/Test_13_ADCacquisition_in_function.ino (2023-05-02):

#include <ADS1115_lite.h>
#include <Ethernet.h>

// Variables for ensuring data is collected at regular time intervals
const unsigned long samplingInterval = 5000;    // How often to take a data sample in ms (must be >25ms, since this is time needed to update OLED screen in loop)
unsigned long previousSampledMillis = 0;        // Time at which previous sample was acquired
unsigned long currentMillis = 0;                // Current time elapsed since program started in ms

ADS1115_lite adc(ADS1115_DEFAULT_ADDRESS); //Initializes wire library, sets private configuration variables to ADS1115 default(2.048V, 128SPS, Differential mode between  AIN0 and AIN1.  The Address parameter is not required if you want default
int16_t Raw;
const int N = 20;
long Raw_runningsum;

////// ETHERNET VARIABLES /////
EthernetClient client;
byte mac[] = { 0xDE, 0xAD, 0xBE, 0xEF, 0xFE, 0xEB };

IPAddress SERVER_NAME(192, 168, 0, 19);
int    SERVER_PORT = 8086;
String INFLUXDB_DATABASE = "arduino";
String INFLUXDB_USERNAME = "arduino";
String INFLUXDB_PASSWORD = "physics1234";
String HTTP_METHOD = "POST";

String SERVER_NAME_STR = String(SERVER_NAME[0]) + "." + SERVER_NAME[1] + "." + SERVER_NAME[2] + "." + SERVER_NAME[3] ;
String endPoint = "/write?db=" + INFLUXDB_DATABASE + "&u=" + INFLUXDB_USERNAME + "&p=" + INFLUXDB_PASSWORD;

String payload = "";  //data for HTTP Post;
char response_buffer[500];
int index = 0;
int response_code;
///////////////////////////////////////////////////////

float average_counts;
float Bfield_X_Sensorvoltage;
float Bfield_Y_Sensorvoltage;
float Bfield_Z_Sensorvoltage;
float Bfield_X;
float Bfield_Y;
float Bfield_Z;
float T;

float microTeslaPerVolt = 1.0; // Should be 7 uT/V for real device


void setup() {
  Serial.begin(57600);

  pinMode(10, OUTPUT); // SPI SS pin for most Arduino models (need to connect)
  Ethernet.begin(mac); // Putting only mac here means dhcp will be used (and assigned ip address will appear in router table)

  delay(1000); // Allow ethernet chip time to initialise

  adc.setGain(ADS1115_REG_CONFIG_PGA_4_096V);
  adc.setSampleRate(ADS1115_REG_CONFIG_DR_860SPS); //Set the slowest and most accurate sample rate
  Wire.setClock(400000);

}

void loop() {

  currentMillis = millis();

  // When sampling interval has elapsed, go into this loop and take data points ////////////////////////////////////
  if ((currentMillis - previousSampledMillis) >= samplingInterval) {

    // Read Channel #1 ///////////////////
    average_counts = collect_ADC_averagecounts(0);
    Bfield_X_Sensorvoltage = (average_counts - 16234.7057) / 1597.761647;
    Bfield_X = Bfield_X_Sensorvoltage * microTeslaPerVolt;
    //////////////////////////////////////

    // Read Channel #2 ///////////////////
    average_counts = collect_ADC_averagecounts(1);
    Bfield_Y_Sensorvoltage = (average_counts - 16234.7057) / 1597.761647;
    Bfield_Y = average_counts * 0.000125;
    //////////////////////////////////////

    // Read Channel #3 ///////////////////
    average_counts = collect_ADC_averagecounts(2);
    Bfield_Z_Sensorvoltage = (average_counts - 16234.7057) / 1597.761647;
    Bfield_Z = average_counts * 0.000125;
    //////////////////////////////////////

    T = 22.16;

    // Construct InfluxDB payload
    String payload = "fluxgate BX=" + String(Bfield_X, 5) + ",BY=" + String(Bfield_Y, 5) + ",BZ=" + String(Bfield_Z, 5) + ",T=" + String(T, 2);

    // Send values to remote InfluxDB database
    response_code  = post_data_to_influxdb(payload); // Takes 25 ms to connect, post data, and read response

    previousSampledMillis += samplingInterval; // Keep track of last time that a sample was taken
  }

}


float collect_ADC_averagecounts(int channel) {
  
  switch (channel) {
  case 0: 
    adc.setMux(ADS1115_REG_CONFIG_MUX_SINGLE_0); //Set single ended mode between AIN0 and GND
    break;
  case 1: 
    adc.setMux(ADS1115_REG_CONFIG_MUX_SINGLE_1); //Set single ended mode between AIN1 and GND
    break;
  case 2: 
    adc.setMux(ADS1115_REG_CONFIG_MUX_SINGLE_2); //Set single ended mode between AIN2 and GND
    break;
  }
  
  Raw_runningsum = 0;
  for (int i = 0; i < N; i++) {
    adc.triggerConversion(); //Start a conversion.  This immediatly returns
    Raw = adc.getConversion(); //This polls the ADS1115 and wait for conversion
    Raw_runningsum = Raw_runningsum + Raw;
  }
  average_counts = (float)Raw_runningsum / (float)N ;
  return average_counts;
}

int post_data_to_influxdb(String payload) {

  // Make a HTTP request to the InfluxDB server
  client.connect(SERVER_NAME, SERVER_PORT);
  while (!client.connected()) {
    // IMPLEMENT TIMEOUT HERE
  }

  client.println("POST " + endPoint + " HTTP/1.1");
  client.println("Host: " + SERVER_NAME_STR + ":" + String(SERVER_PORT));
  client.println("User-Agent: Arduino/1.6");
  client.println("Connection: close"); // It's possible to use "keep-alive" here instead
  client.println("Content-Type: application/x-www-form-urlencoded;");
  client.print("Content-Length: ");
  client.println(payload.length());
  client.println();
  client.println(payload);

  // Wait for a response from the server
  while (!client.available()) {
    // IMPLEMENT TIMEOUT HERE
  }

  // Read response from server (takes around 10 ms)
  while (client.available()) {
    char c = client.read();
    if (index < 499) {
      response_buffer[index] = c;
      index++;
      response_buffer[index] = '\0';
    }
  }

  //Serial.println(response_buffer);
  client.stop();

  // Return response code (204=success, 401=unauthorized, ... etc)
  String response_code_string = String(response_buffer[9]) + response_buffer[10] + response_buffer[11];
  return response_code_string.toInt();
}

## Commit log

2023-05-15 Started UDP implementation and timer interrupt
2023-05-18 Issue fixed reading of adcs moved to main loop and posting left in timer
    [main.ino]
2023-05-19 Fixed display issue and changed Ports
    [main.ino]
2023-05-25 Added CAD model for a case using FreeCAD
    [Environment_Monitor_Case-Case Lid.stl, Environment_Monitor_Case-Main Frame.stl, Standoff mf - M3 x 6 across flats 5mm.step]
2023-05-25 Fixed typo
    [Environment_Monitor_Case-Case Lid.stl, Environment_Monitor_Case-Main Frame.stl, Standoff mf - M3 x 6 across flats 5mm.step]
2023-05-25 Added FreeCAD model of case
    [Environment_Monitor_Case-Case Lid.stl, Environment_Monitor_Case-Main Frame.stl, Standoff mf - M3 x 6 across flats 5mm.step]
